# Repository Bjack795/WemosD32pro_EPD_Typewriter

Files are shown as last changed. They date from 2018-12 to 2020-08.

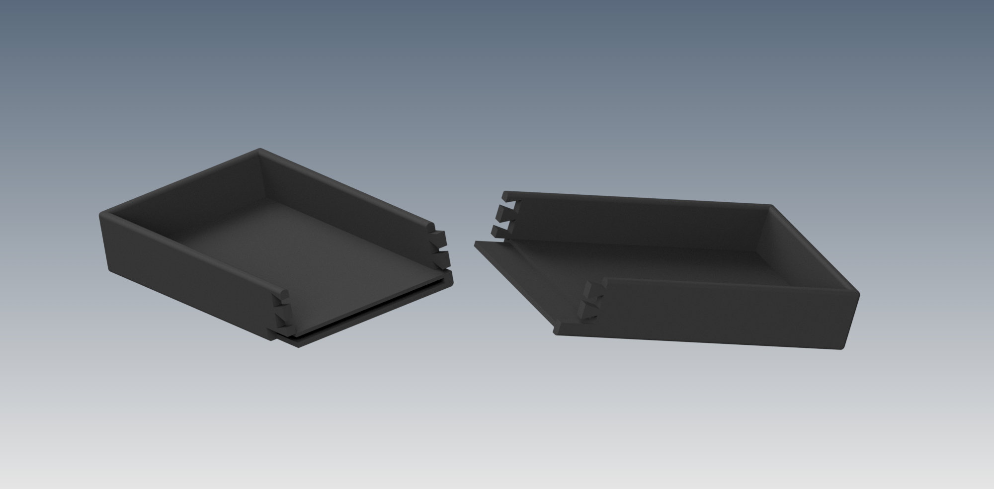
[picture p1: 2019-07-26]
Case/Case 3Dprinted/A/CaseA.png

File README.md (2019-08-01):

# WemosD32pro_EPD_Typewriter
This is a rudimental typewriter using Wemos D32 pro, a Waveshare ePaper 2.9" and a USB host for the keyboard

## Hardware

- Wemos D32 pro (https://wiki.wemos.cc/products:d32:d32_pro)
- 296x128, 2.9inch E-Ink display module (https://www.waveshare.com/product/2.9inch-e-paper-module.htm)
- Keyboard USB Host (http://www.hobbytronics.co.uk/usb-host-keyboard)
- wires, headers and resistances
- microSD
- TP4056
- AAA rechargeable batteries 
- mechanical keyboard

The schematics of the connections are in the EPD_TYPEWRITER_Connections.pdf file
EPAPER_TYPEWRITER_Connections

## Software
All the libraries and files included in TYPEWRITER_EPD folder and downloaded from the library manager.

Arduino IDE must be used to upload all these files.

**REMEMBER**

Add "esp32" in Board Manager of Arduino IDE or follow this https://github.com/espressif/arduino-esp32/blob/master/docs/arduino-ide/windows.md procedure to have the latest commits (this should fix some bugs).
Then select Lolin D32 pro from the boards list.

### EPD library Rights

All the EPD functions rights belong to ZinggJM (https://github.com/ZinggJM), a genius whose patience and knowledge has been of incredible help in bringing this project up to light.

The functions are an implementation of this library https://github.com/ZinggJM/GxEPD2 and of Adafruit GFX library https://github.com/adafruit/Adafruit-GFX-Library.

### WebServer Rights

All the WebServer functions rights belong to G6EJD (https://github.com/G6EJD), a genius to whom goes my gratitude for the huge help given to this project, follow him here https://www.youtube.com/user/G6EJD, it's worth it.

The functions are an implementation of this library https://github.com/tzapu/WiFiManager/tree/development and of the standard Webserver.h built-in library.

## Still a prototype
This is the actual aspect of the project.





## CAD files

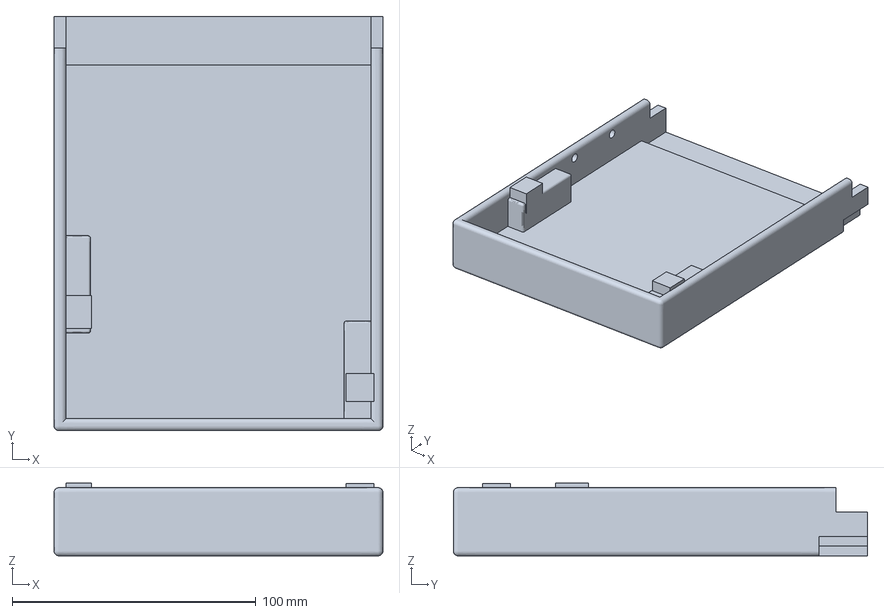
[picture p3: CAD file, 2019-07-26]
Case/Case 3Dprinted/A/CE3_Case_A1.3mf
135.0 x 170.0 x 29.8 mm

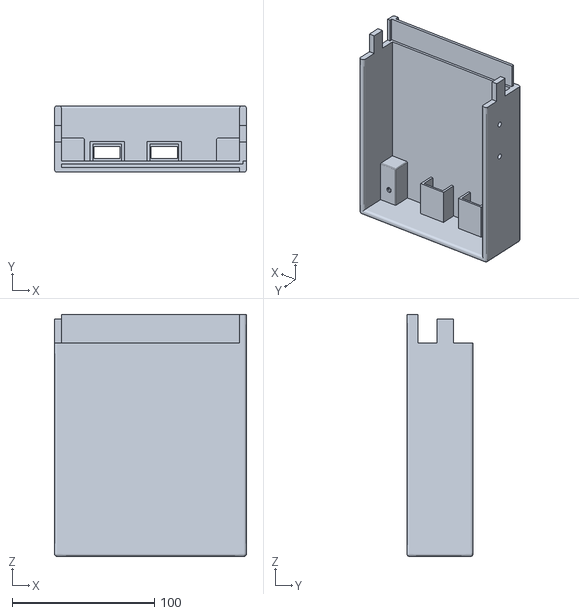
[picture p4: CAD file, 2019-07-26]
Case/Case 3Dprinted/B/Case_B2_print.stl
135.0 x 46.7 x 170.0

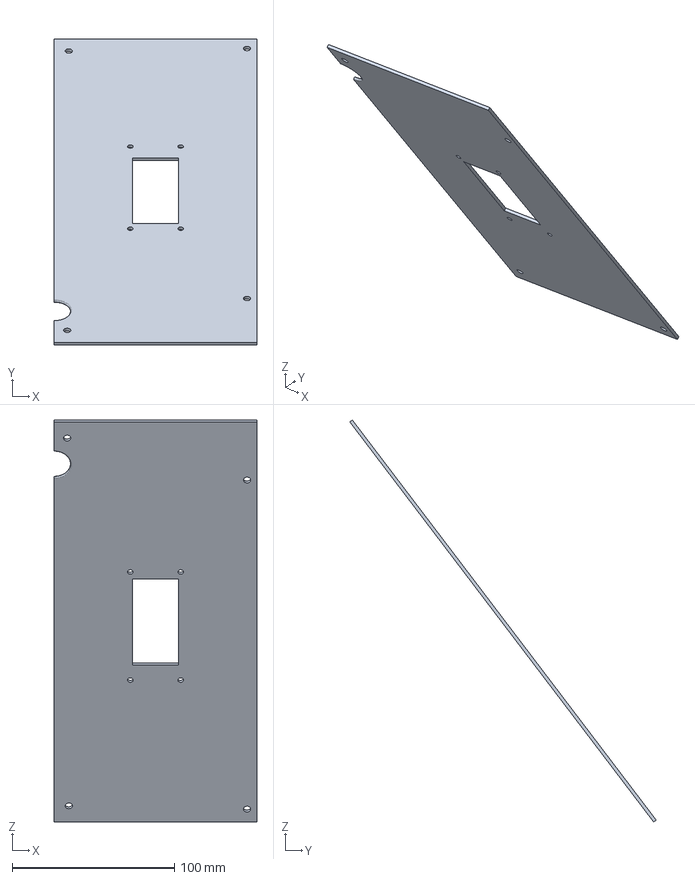
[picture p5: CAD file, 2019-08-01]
Case/Case 3Dprinted/Placca B/CE3_PlaccaB.3mf
125.0 x 189.1 x 248.1 mm

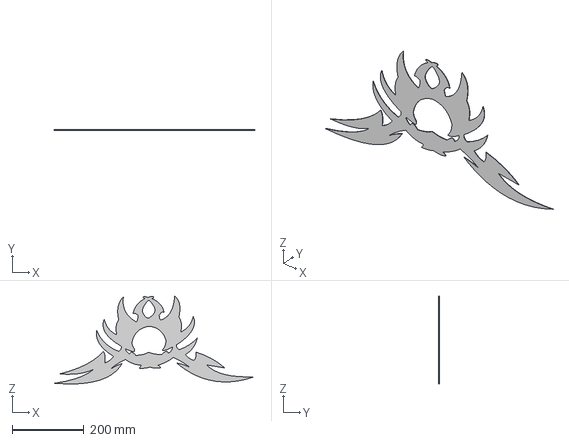
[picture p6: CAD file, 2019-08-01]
Case/Case 3Dprinted/Placchetta/Logo.step
558.4 x 1.00 x 245.4 mm

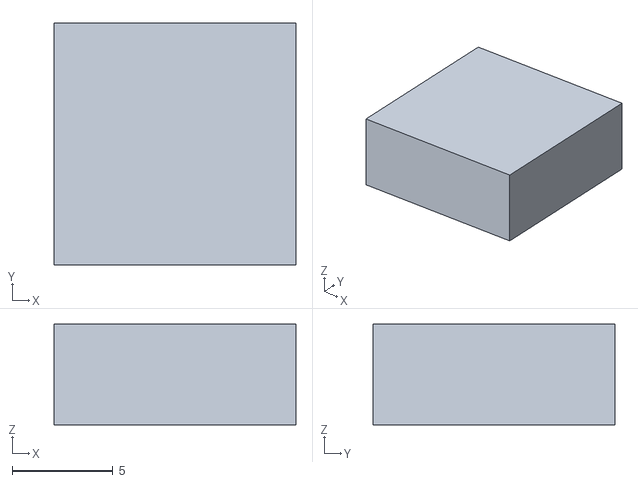
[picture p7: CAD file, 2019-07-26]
Case/Case 3Dprinted/Prove/Incastri.stl
12.0 x 12.0 x 5.00

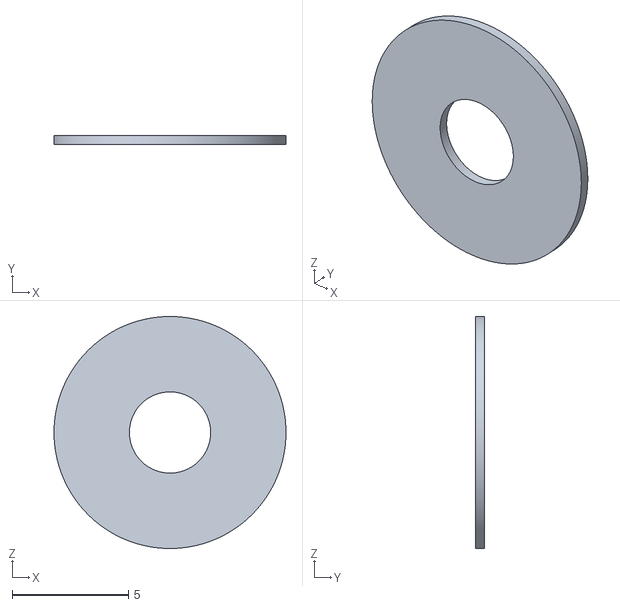
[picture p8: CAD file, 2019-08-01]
Case/Case 3Dprinted/Rondella/Rondella.stl
10.00 x 0.4 x 10.00

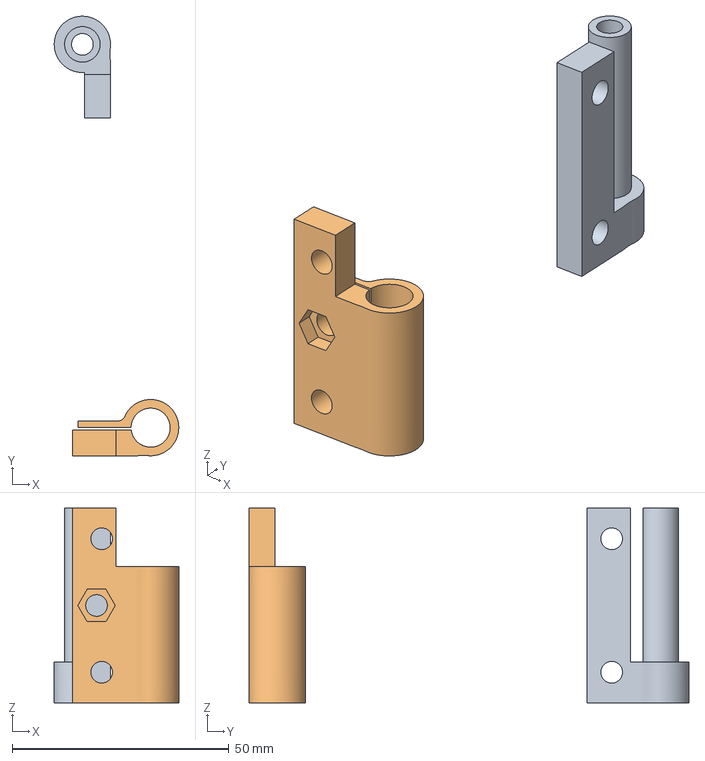
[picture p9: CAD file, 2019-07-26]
Case/Cerniera/CE3_Cerniera 4.3mf
28.7 x 101.5 x 45.0 mm

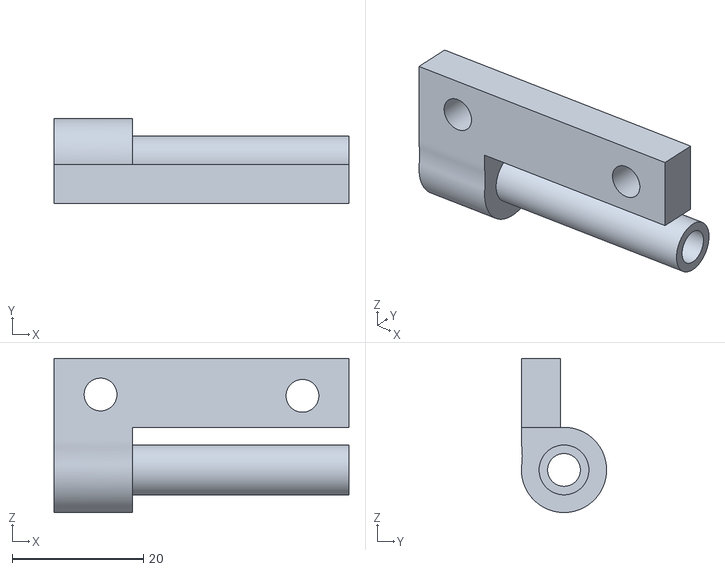
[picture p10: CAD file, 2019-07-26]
Case/Cerniera/Definitiva/Cerniera_ins.stl
45.0 x 13.0 x 23.5

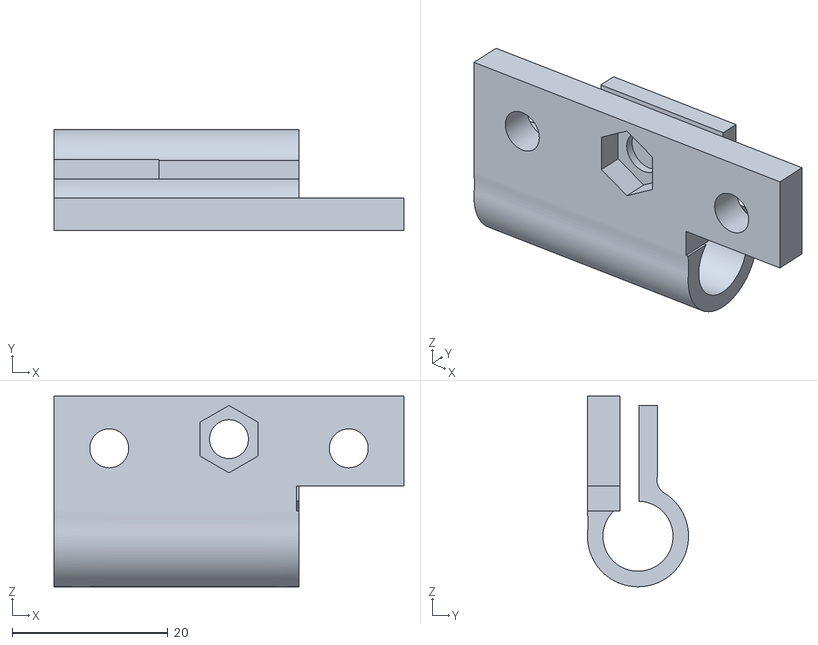
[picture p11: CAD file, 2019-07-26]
Case/Cerniera/Versione 3/Cerniera 5.stl
45.0 x 13.0 x 24.5

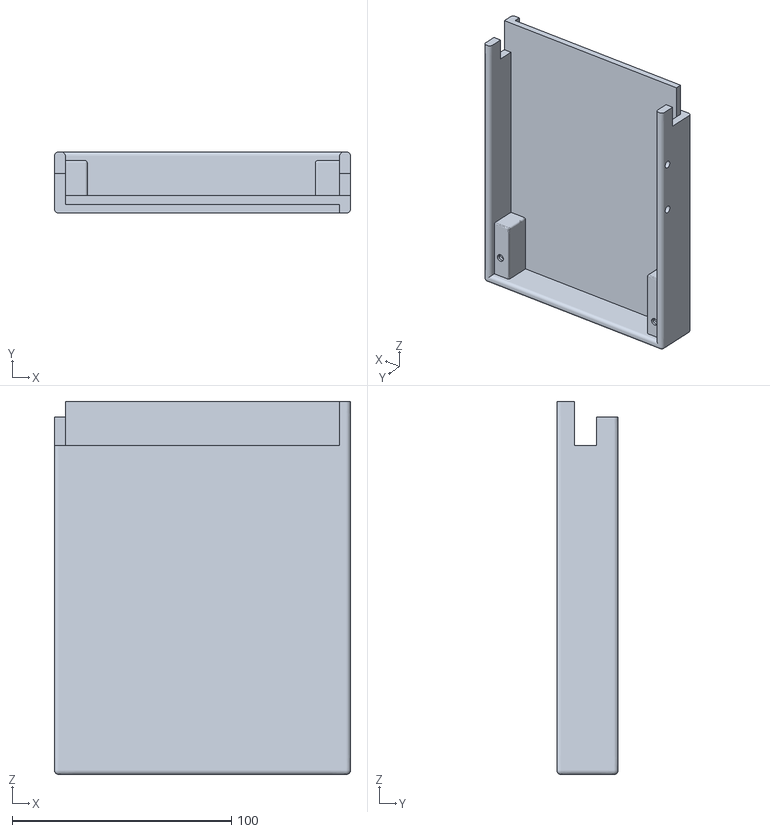
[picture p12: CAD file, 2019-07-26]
Case/Case 3Dprinted/A/Case_A2.stl
135.0 x 28.0 x 170.0

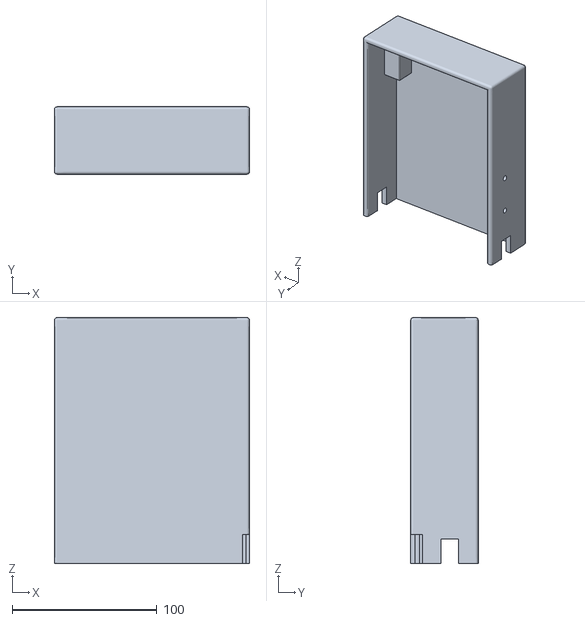
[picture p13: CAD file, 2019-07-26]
Case/Case 3Dprinted/B/Case_B1.stl
135.0 x 46.7 x 170.0

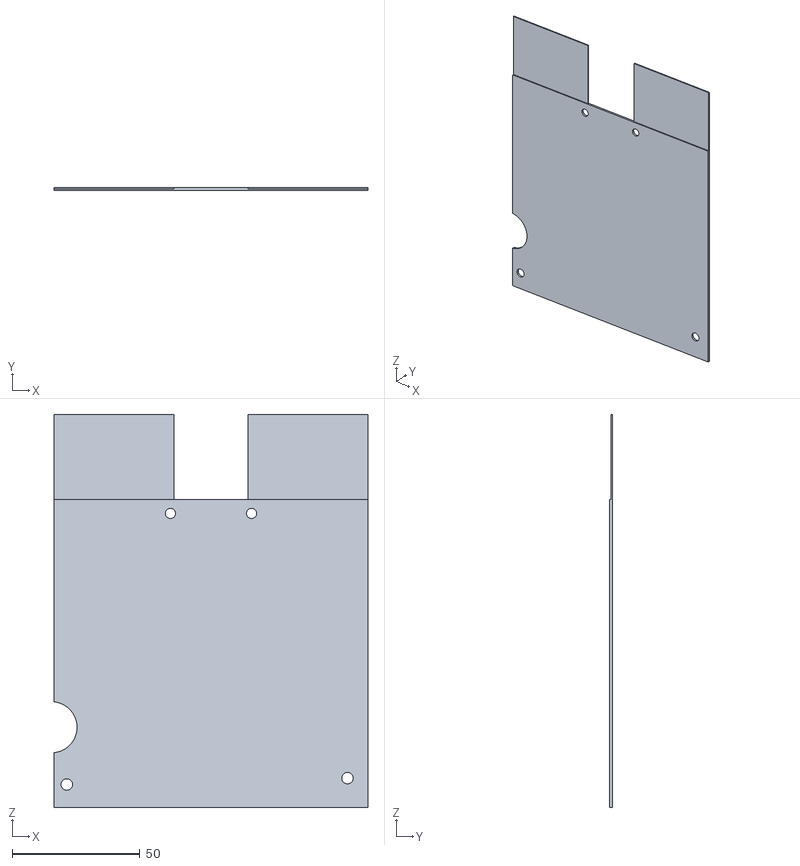
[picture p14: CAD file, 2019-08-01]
Case/Case 3Dprinted/Placca B/PlaccaB_2.stl
123.0 x 1.00 x 154.0

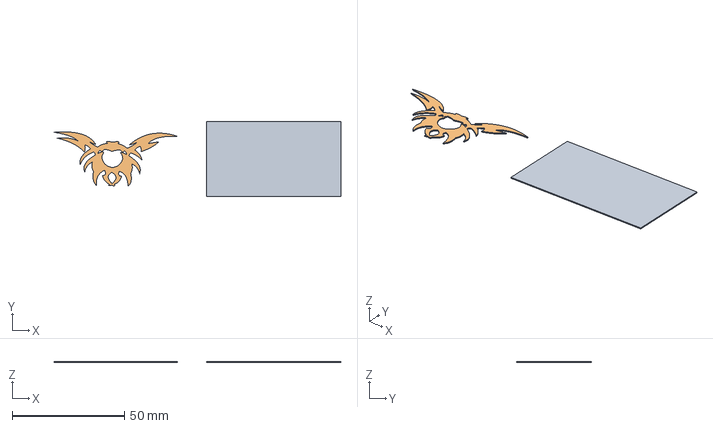
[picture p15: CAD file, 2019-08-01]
Case/Case 3Dprinted/Placchetta/CE3_Placchetta.3mf
128.0 x 33.3 x 0.4 mm

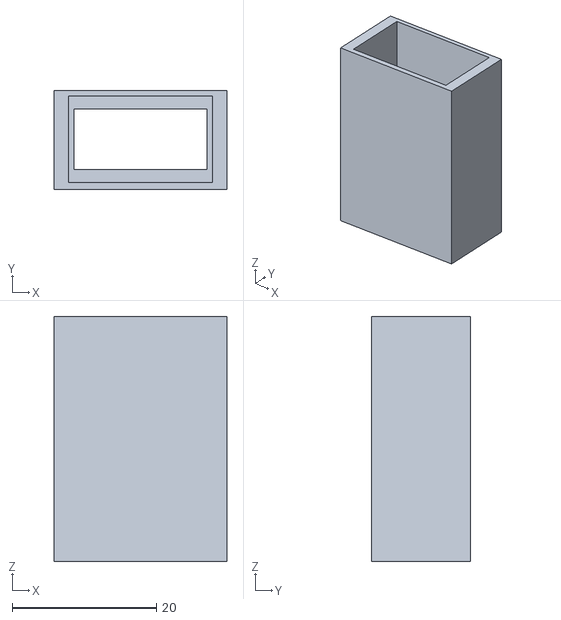
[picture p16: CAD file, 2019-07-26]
Case/Case 3Dprinted/Prove/USB.stl
24.0 x 13.8 x 34.0

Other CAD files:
Case/Cerniera/Cerniera 2.stl
Case/Cerniera/Definitiva/Cerniera_cov.stl
Case/Cerniera/Versione 3/Cerniera 5.5.stl
Case/Case 3Dprinted/A/Case_A1.stl
Case/Case 3Dprinted/A/CE3_Case_A2.3mf
Case/Case 3Dprinted/A/CaseA.iam
Case/Case 3Dprinted/A/CaseA.ipn
Case/Case 3Dprinted/A/Case_A1.ipt
Case/Case 3Dprinted/A/Case_A2.ipt
Case/Case 3Dprinted/A/OldVersions/CaseA.0021.iam
Case/Case 3Dprinted/A/OldVersions/Case_A1.0029.ipt
Case/Case 3Dprinted/A/OldVersions/Case_A2.0031.ipt
Case/Case 3Dprinted/B/CE3_Case_B1.3mf
Case/Case 3Dprinted/B/Case B.iam
Case/Case 3Dprinted/B/Case_B1.ipt
Case/Case 3Dprinted/B/Case_B2.ipt
Case/Case 3Dprinted/B/Case_B2_print.ipt
Case/Case 3Dprinted/B/OldVersions/Case B.0001.iam
Case/Case 3Dprinted/B/OldVersions/Case_B1.0030.ipt
Case/Case 3Dprinted/B/OldVersions/Case_B2.0042.ipt
Case/Case 3Dprinted/B/OldVersions/Case_B2.0043.ipt
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

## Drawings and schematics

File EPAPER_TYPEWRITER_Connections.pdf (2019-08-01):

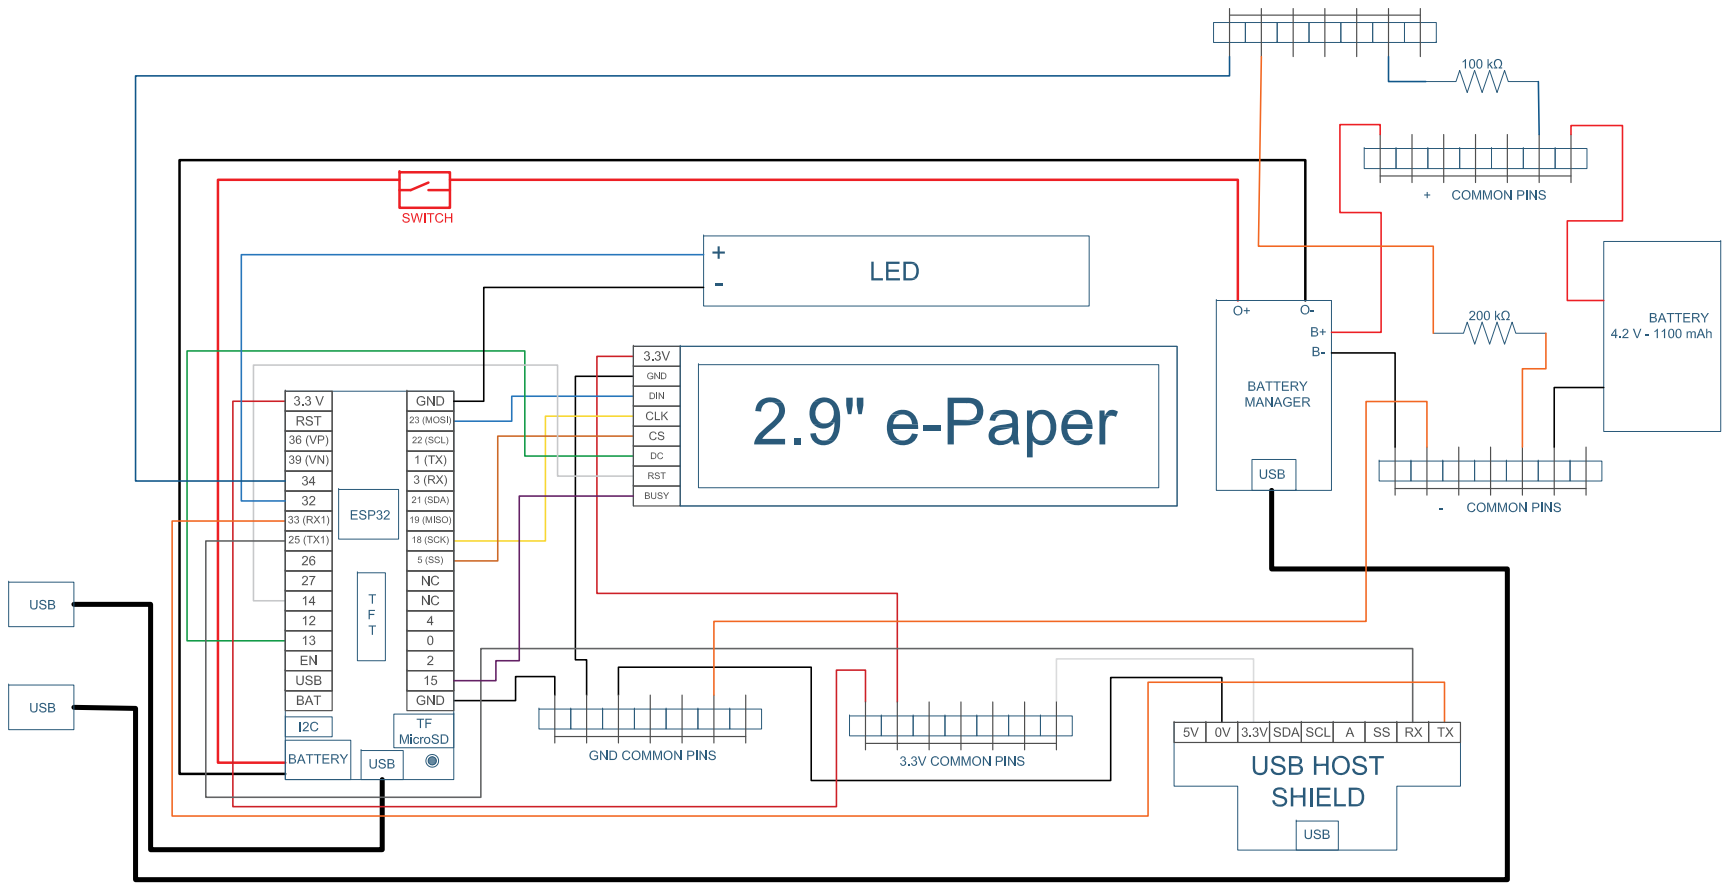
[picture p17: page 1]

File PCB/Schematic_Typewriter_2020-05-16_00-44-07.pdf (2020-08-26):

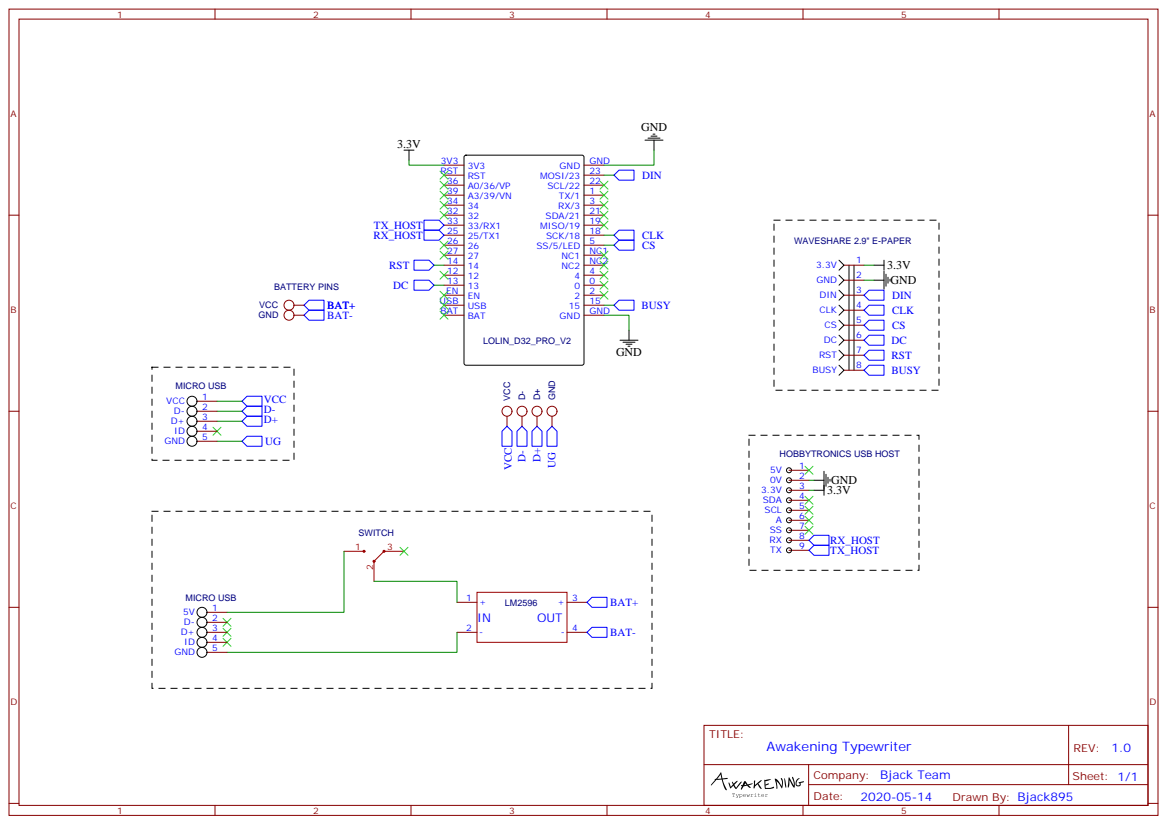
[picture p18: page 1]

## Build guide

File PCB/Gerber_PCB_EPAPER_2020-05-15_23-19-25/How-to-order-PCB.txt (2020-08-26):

How to Order PCB

Please refer to:
https://docs.easyeda.com/en/PCB/Order-PCB

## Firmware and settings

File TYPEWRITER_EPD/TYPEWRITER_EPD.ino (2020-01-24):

//TYPEWRITER.ino
#include <SD.h>
#include <EEPROM.h>
#define ArrayCount(array) (sizeof array / sizeof array[0])
//ArrayCount(myarray) --> rows
//ArrayCount(myarray[0]) --> rows
/////////////////////////////////////////////////////////////////////////////////////////////
  #include <WiFiManager.h> 
////////////////////////////////////////////////////////////////////////
  #include <WiFi.h>              // Built-in
  #include <WebServer.h>
  #include <ESPmDNS.h>
  #include "FS.h"
  #include "Sys_Variables.h"
  #include "CSS.h"
  #include <SD.h> 
  #include <SPI.h>
  WebServer server(80);
void Webserver_setup();
void Webserver_loop();
void copy_file(String pathold, String pathnew);
void cursor_file(String pathsave);
WiFiManager wm;
///////////////////////////////////////////////////////////////////////////////////////////////////////////////////////////////////////////////
#define PIN_RX 33
#define PIN_TX 25
//devono essere pin digitali
int FLAG_ESC=0;
HardwareSerial Tastiera(1);
/////////////////////////////////////////////////////////////////////////////////////////////////////////////////////////////////SCREEN
#define ENABLE_GxEPD2_GFX 0
#define A_PIN 32
#define RES_PIN 34
#define PIN_RX 33
#define PIN_TX 25
#include <GxEPD2_BW.h>
#include <Fonts/FreeMonoBold9pt7b.h>
#include "DATABASE_bitmaps.h" 
#define XRES 296
#define YRES 128
#define SPAZIATURA    1
#define INTERLINEA    3
#define MARGINE_DX_STD    10*SPAZIATURA
#define MARGINE_SX_STD    10*SPAZIATURA
#define MARGINE_UP_STD    6*INTERLINEA
#define MARGINE_DOWN_STD  6*INTERLINEA
#define TIMEOUT 100

GxEPD2_BW<GxEPD2_290, GxEPD2_290::HEIGHT> display(GxEPD2_290(/*CS=5*/ 5, /*DC=*/ 13, /*RST=*/ 14, /*BUSY=*/ 15));

/////////////////////////////////////////////////////////////////////////////////////////////////////////////////////////////////////////////////
String ANSWER;
File TEMPFILE;
File NEWFILE;
String PATHTEMP = "/Settings/temp.txt";
String PATHCURSOR = "/Settings/cursor_file.txt";
String PATHTESTI = "/Testi";
String PATHSETTINGS = "/Settings";
String CONNECTED_WIFI;
String PASSPORT_IP;
const char SERVER_NAME[] = "BjackWiFi";
//bool RESET_WIFI = false;
bool OK_WIFI = false;
bool OK_SERVER = false;
bool INSIDE = false; //check if I can search for wifi
float voltage;
int SAVE_TRIGGER = -1;
/////////////////////////////////////////////////
#define MAXLINES 10000
int MAX_HEIGHT = 0;
int MAX_WIDTH = 0;
int MIN_Y1 = 0;
int INGOMBRO;
int RES_LINES;
int RES_WIDTH;
int MARGINE_DX = MARGINE_DX_STD;
int MARGINE_SX = MARGINE_SX_STD;
int MARGINE_UP = MARGINE_UP_STD;
int MARGINE_DOWN = MARGINE_DOWN_STD;
int MARGINE_PROVA;
int LUCE = 1;
int YPAG = 0, XCUR = 0, YCUR = 0;
/////////////////////////////////////////////////
int LEVEL = -8;
int PREV_LEV = -8;
char MAIN_MENU [][XRES-4*SPAZIATURA] = {"Open","New", "Settings","Restart"};
char SETTINGS_MENU [][XRES-4*SPAZIATURA] = {"Margins","Wifi"};
char SAVE_MENU [][XRES-4*SPAZIATURA] = {"Save","Don't save"};
char WIFI_MENU [][XRES-4*SPAZIATURA] = {"Info","Portal"};
int CHOSEN = 0;
int OPTION;

//////////////
char LISTA [50][XRES-4*SPAZIATURA];
int LENG = 0;
int TITOLO;
int LAST_LEVEL;
int CRYPTO = -1;
String PREV_LOC;
int LINEE [MAXLINES];
int LINEE_LUNG = 0;
String TEXT_NAME;
bool IS_OLD;
int LENG_NEW = 0;
char entry_1[XRES-4*SPAZIATURA];
/////////////////////////////

void setup() {
  Serial.begin(115200);
  EEPROM.begin(32);
  pinMode(35,INPUT);
//  esp_sleep_enable_ext0_wakeup(GPIO_NUM_36, 0);
//  print_wakeup_reason();
  btStop();
  Tastiera.begin(115200,SERIAL_8N1, PIN_RX, PIN_TX);
  display.init(115200);
  display.setRotation(1);
  display.setFont(&FreeMonoBold9pt7b);
  maxminHeight(); 
  maxCharWidth(); 
  INGOMBRO = MAX_HEIGHT+abs(MIN_Y1);
  RES_LINES = (YRES-MARGINE_UP+INTERLINEA)/(INGOMBRO+INTERLINEA)+1;
  RES_WIDTH = (XRES-MARGINE_SX+SPAZIATURA)/(MAX_WIDTH+SPAZIATURA);
  //attachInterrupt(digitalPinToInterrupt(36),sleepFunction, RISING);
  EEPROM.get(0,MARGINE_PROVA);
  if(MARGINE_PROVA>4)
  {
    EEPROM.get(0,MARGINE_DX);
    EEPROM.get(4,MARGINE_SX);
    EEPROM.get(8,MARGINE_UP);
    EEPROM.get(16,MARGINE_DOWN);
  }
  Serial.println(RES_WIDTH);
  delay(50);
  initializeSD();
  for (int i = 0; i<2; i++)
  {
    Webserver_autoconnect(2);
    if(OK_WIFI == true) break;
  }
  ledcAttachPin(A_PIN, 1);
  ledcSetup(1, 12000, 8);
  //pinMode(RES_PIN, OUTPUT);
  paginaBianca();
  if(!SD.exists(PATHSETTINGS))
  {
    SD.mkdir(PATHSETTINGS);

  }
   if(!SD.exists(PATHTESTI))
  {
    SD.mkdir(PATHTESTI);
  }
   if(!SD.exists(PATHCURSOR))
  {
    TEMPFILE = SD.open(PATHCURSOR, FILE_WRITE);
    TEMPFILE.close();
  }
 voltaggio();
 delay(50);
}

void loop() {

  //***************************************************************** Level WALPAPER (-8)
  if(LEVEL == -8)
  {
    PREV_LEV = -8; 
    disegnaWallpaper(screen1);
    while(LEVEL == -8)
    {
    ANSWER = keyboard_loop();
    if(ANSWER == "[Enter]")
    {
      LEVEL = 0;
    }
    Webserver_loop();
    ledcWrite(1, (120+LUCE*120));
    }
  }
  Webserver_loop();
  ledcWrite(1, (120+LUCE*120));  
  
  //*************************************************************** Level MAIN MENU (0)
  if (LEVEL == 0) //In the main menu
  { PREV_LEV = -8; 
    OPTION = choose_page(ArrayCount(MAIN_MENU), MAIN_MENU); 
    if(CHOSEN == 1)
    {
    if(OPTION == 0)
    {LEVEL = 100;} //choose the file
    else if(OPTION == 1)
    {LEVEL = 300;} //write the name of the new file
    else if(OPTION == 2)
    {LEVEL = 10;} //settings
    else if(OPTION == 3)
    {
      display.setTextColor(GxEPD_BLACK);
      display.setFullWindow();
      display.fillScreen(GxEPD_WHITE);
      display.setCursor(MARGINE_SX,0*(INGOMBRO+INTERLINEA)+ MARGINE_UP);
      display.print("Restarting...");
      display.display(true);
      delay(1000);
      ESP.restart();
    } //restart
    }
  }

  //**************************************************************** Level CHOICE OF THE FILE (100-199)
  else if (LEVEL > 99 and LEVEL <200) //choice of the file
  { PREV_LEV = 0; 
    if (CHOSEN == 1)
    {
      if((String)(MAIN_MENU[OPTION]) == "Open")
      { TITOLO = open_file("/Testi",&LENG,LISTA);
      }
        IS_OLD = true; //I'm opening an old file
     }
  }
  
  //**************************************************************** Level NEW FILE (300)
  else if (LEVEL == 300) //I have to create a new file
    {
      PREV_LEV = 0; 
      LENG_NEW = insert_name(entry_1); 
      IS_OLD = false;
    }
    
 //***************************************************************** Level TEXT (500)
  else if (LEVEL == 500) //inside a text
  {  if(IS_OLD == true) //I'm opening an existent file
      {
        TEXT_NAME = "/Testi/"+(String)(LISTA[TITOLO]);
        char text_name_char[TEXT_NAME.length()];
        TEXT_NAME.toCharArray(text_name_char,TEXT_NAME.length()+1); //string to char array
        cursor_file_read(text_name_char);
      }
    else //new file
    { 
      String entry_2; //char to string
      for (int i = 0; i<LENG_NEW;i++)
      {
        if((int)(entry_1[i])== 32) { entry_1[i] = (char)(95);}
        entry_2 +=entry_1[i];        
      }     
        TEXT_NAME = "/Testi/"+ entry_2 +".txt";
        Serial.println(TEXT_NAME);
        char text_name_char[TEXT_NAME.length()];
        TEXT_NAME.toCharArray(text_name_char,TEXT_NAME.length()+1); //string to char
        cursor_file_save(text_name_char);
        NEWFILE = SD.open(TEXT_NAME, FILE_WRITE);
        NEWFILE.close();
        LAST_LEVEL = 0;
        XCUR = 0;
        YCUR = 0;
        YPAG = 0;
      
    }    
      print_page(TEXT_NAME);  
  }
  
   //***************************************************************** Level SETTINGS (10)
  else if (LEVEL == 10)
  {
    PREV_LEV = 0;
    OPTION = choose_page(ArrayCount(SETTINGS_MENU), SETTINGS_MENU); 
    if(CHOSEN == 1)
    {
    if(OPTION == 0)
    {PREV_LEV = LEVEL; LEVEL = 11;   } //margins
    else if(OPTION == 1)
    {PREV_LEV = LEVEL; LEVEL = 12; } //wifi
    }   
  }
  //***************************************************************** Level MARGINS (11)
  else if (LEVEL == 11)
  {
    PREV_LEV = 10;
    marginFunction();
  }
   //***************************************************************** Level WIFI (12)
  else if (LEVEL == 12)
  {
    PREV_LEV = 10;
    OPTION = choose_page(ArrayCount(WIFI_MENU), WIFI_MENU); 
    if(CHOSEN == 1)
    {
    if(OPTION == 0)
    {PREV_LEV = 12; LEVEL = 13;   } //margins
    else if(OPTION == 1)
    {PREV_LEV = 12; LEVEL = 14;   } //wifi
    }   
  }
    //***************************************************************** Level INFO (13)
  else if (LEVEL == 13)
  {
    wifiInfoFunction();
    
  }
   //***************************************************************** Level PORTAL (14)
  else if (LEVEL == 14)
  {
    wifiPortalFunction();
    
  }
  


}

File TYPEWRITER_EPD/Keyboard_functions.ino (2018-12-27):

//Keyboard_functions.ino

String keyboard_loop() {
  String risposta;
  
    int inByte = Tastiera.read();  
    if(inByte == 27)
    {
       FLAG_ESC = 1;
       risposta = ("[Esc]");
    }   
    else
    {
      if(FLAG_ESC==1)
      {
        // Previous char was ESC - Decode all the escaped keys
        switch(inByte)
        {
            case 0x49:
              risposta = ("[PgUp]");
              break;
            case 0x51:
              risposta = ("[PgDn]");
              break;    
            case 0x47:
              risposta = ("[Home]");
              break;
            case 0x4F:
              risposta = ("[End]");
              break;     
            case 0x52:
              risposta = ("[Ins]");
              break;
            case 0x53:
              risposta = ("[Del]");
              break;               
            case 0x3B:
              risposta = ("[F1]");
              break;
            case 0x3C:
              risposta = ("[F2]");
              break;    
            case 0x3D:
              risposta = ("[F3]");
              break;
            case 0x3E:
              risposta = ("[F4]");
              break;     
            case 0x3F:
              risposta = ("[F5]");
              break;
            case 0x40:
              risposta = ("[F6]");
              break;          
            case 0x41:
              risposta = ("[F7]");
              break; 
            case 0x42:
              risposta = ("[F8]");
              break; 
            case 0x43:
              risposta = ("[F9]");
              break; 
            case 0x44:
              risposta = ("[F10]");
              break; 
            case 0x57:
              risposta = ("[F11]");
              break; 
            case 0x58:
              risposta = ("[F12]");
              break;     
            case 0x48:
              risposta = ("[Up]");
              break; 
            case 0x50:
              risposta = ("[Down]");
              break; 
            case 0x4B:
              risposta = ("[Left]");
              break; 
            case 0x4D:
              risposta = ("[Right]");
              break;         
            case 0x54:
              risposta = ("[Print]");
              break; 
            case 0x5B:
              risposta = ("[Windows]");
              break;  
            case 13:
              risposta = ("[Enter]");
              break;   
            default:
              risposta = ("[?]");
              break;            
        }
        FLAG_ESC=0;    
      }
      else
      {  

        if(inByte==1)
        {
           risposta = ("Control-A");
        }  
        else if(inByte==2)
        {
           risposta = ("Control-B");
        }
        else if(inByte==3)
        {
           risposta = ("Control-C");
        }
        else if(inByte==4)
        {
           risposta = ("Control-D");
        }
        else if(inByte==5)
        {
           risposta = ("Control-E");
        }
        else if(inByte==6)
        {
           risposta = ("Control-F");
        }
        else if(inByte==7)
        {
           risposta = ("Control-G");
        }
        // Dont decode 8 - backspace
        else if(inByte==8)
        {
           risposta = ("Backspace");
        }
        else if(inByte==9)
        {
           risposta = ("Tab");
        }
        // Dont decode 10 - Line Feed
        else if(inByte==11)
        {
           risposta = ("Control-K");
        }
        else if(inByte==12)
        {
           risposta = ("Control-L");
        }
       else if(inByte==13)
        {
           risposta = ("[Enter]");
        }
        else if(inByte==14)
        {
           risposta = ("Control-N");
        }
        else if(inByte==15)
        {
           risposta = ("Control-O");
        }
        else if(inByte==16)
        {
           risposta = ("Control-P");
        }
        else if(inByte==17)
        {
           risposta = ("Control-Q");
        }
        else if(inByte==18)
        {
           risposta = ("Control-R");
        }
        else if(inByte==19)
        {
           risposta = ("Control-S");
        }
        else if(inByte==20)
        {
           risposta = ("Control-T");
        }
        else if(inByte==21)
        {
           risposta = ("Control-U");
        }
        else if(inByte==22)
        {
           risposta = ("Control-V");
        }
        else if(inByte==23)
        {
           risposta = ("Control-W");
        }
        else if(inByte==24)
        {
           risposta = ("Control-X");
        }
        else if(inByte==25)
        {
           risposta = ("Control-Y");
        }        
        else if(inByte==26)
        {
           risposta = ("Control-Z");
        }

        else   
        {
          // Its a normal key
          risposta = (String)(char)(inByte);
        }  
      }
    }  
    return risposta;
   
}

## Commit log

2019-02-20 Margins page in settings and corrected SS to 5 after the update
    [GUI_functions.ino, TYPEWRITER_EPD.ino]
2019-04-30 Pin 12 issues
    Pin 12 seems to give some errors so it has been moved to 13
